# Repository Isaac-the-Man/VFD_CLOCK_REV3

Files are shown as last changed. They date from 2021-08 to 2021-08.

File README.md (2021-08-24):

# VFD_CLOCK_REV3
An arduino-compatible IVL2-7/5 VFD clock, version 3.1.

VFD_demo

(NOTE: flashing is only seen on camera due to high FPS)

## Features
- IVL2-7/5 VFD Display
- Arduino-compatible (programmable via Arduino IDE)
- Built-in extremely accurate real time clock with error less than a second per year, with calendar
- Four NeoPixel RGB LED
- On-board push buttons for setting time, changing brightness, LED pattern, and more
- Micro-USB powered
- In-ciruit temperature sensor
- Automatially saves user settings on shutdown
- Power saving mode: automatically lower brightness at night and turns back on in the morning.

## Hardware
- Atmega328P-PU with external 16MHz cyrstal as the MCU.
- FT232RL for USB to TTL converstion (programming the MCU).
- DS3231M+TRL as the RTC. Includes a temperature sensing feedback circuit for tuning the crystal. Error less than a second per year. A CR2032 external power source is used as a back-up power when the USB is not connected.
- WS2812 NeoPixel RGB LED. A serial and individually-addressable RGB LED.
- Adjustable boost converter (AP3012KTR, replaceable): Boost voltage up to 25V. Adjustable via a potentiometer. Highly efficient.
- Adjustable buck converter (ST1S12GR, replaceable): Buck voltage down to 2V. Adjustable via a potentiometer. Highly efficient.
- MAX6921AUI+ VFD driver: 70V high-side switch with integrated 20-bit shift register.

## Usage
Carefully solder each components on the PCB. Insert a CR2032 battery for backup power (critical for time-keeping). Download `VFD_CLOCK_REV3_FINAL.ino` and upload it to the board via USB using the Arduino IDE, and there you have it. There are a lot more settings available in the code (variables starting with `SET_` are configurable at compile time), but requries further investigation of the code.

## Control Button Manual
This document covers the default behavior of the software. For simplicity, ignoring the left most button (RESET), the rest three buttons are referred as `L`, `M`, and `R` from left to right. Button presses shorter than 2 second is a short press, and a long press if longer.

The default display view is the current time (Hour:Minute). The colon in the middle turns on at even second and off during odd. From this state you can perform the following operation:

### SHORT L Press
Display date and year, each two seconds, then return to normal clock mode.

### SHORT M Press
Display temperature from the DS3231 IC for two seconds, then return.

### SHORT R Press
Display "HELO", for fun.

### LONG L Press
Enters time-set mode. The entire VFD display will start to blink. You can then modify Hour:Minute, Month.Date, and Year in a sequence of steps with `M` and `R` changing the values and `L` advancing the modified steps. After setting the year, another `L` press with bring you back to normal clock mode with the new set time.

### LONG M Press
Enters edit brightness mode. Press `L` to decrease lumin and `R` to increase. Value ranges from 1 ~ 25. The VFD or the LED will blink based on whatever is the target of the edit. Pressing `M` will advances into the next step (first VFD -> LED -> back to normal clock mode).

### LONG R Press
Enters edit LED mode. Press `L` to loop between LED patterns (single color cycle -> serial color cycle -> off -> single color cycle...). Press `M` to fix the current color (freezes the color in the cycle). Press `R` to return to normal clock mode.

Software and Hardware designed by *Isaac_the_Man*, aka *Yu-Kai "Steven" Wang*.
Published under MIT LICENSE

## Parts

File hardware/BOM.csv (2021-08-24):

Query | Qty | Manufacturer | MPN | Octopart URL | Part Description | Description | Schematic Reference | Internal Part Number | Lifecycle | Lead Time | RoHS | Total Qty (@ Batch Size: 3) | SKU | SKU | Packaging | Packaging | Unit Price (@ Batch Size: 3) | Unit Price (@ Batch Size: 3) | In Stock | In Stock | MOQ | MOQ | URL | URL | Distributor [Lowest Price (Selected)] | SKU [Lowest Price (Selected)] | Packaging [Lowest Price (Selected)] | Unit Price (@ Batch Size: 3) [Lowest Price (Selected)] | Line Total [Lowest Price (Selected)] | Batch Total [Lowest Price (Selected)] | In Stock [Lowest Price (Selected)] | MOQ [Lowest Price (Selected)] | URL [Lowest Price (Selected)] | Notes
 |  |  |  |  |  |  |  |  |  |  |  |  | Digi-Key | Mouser | Digi-Key | Mouser | Digi-Key | Mouser | Digi-Key | Mouser | Digi-Key | Mouser | Digi-Key | Mouser
AP3012KTR-G1 | 1 | Diodes Inc. | AP3012KTR-G1 | https://octopart.com/ap3012ktr-g1-diodes+inc.-30954658 | AP3012 Series 16 V 500 mA 1.5 MHz Surface Mount Boost DC-DC Converter - SOT-25 |  | U2 |  |  | 48w | Compliant | 3 | AP3012KTR-G1DICT-ND | 621-AP3012KTR-G1 | Cut Tape | Tape & Reel | 16 | 13.697068 | 133601 | 1250 | 1 | 1 | https://octopart.com/click/track?country=TW&ct=offers&ppid=30954658&sid=459&sig=0920746&vpid=95776337&ai4=706 | https://octopart.com/click/track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 | Mouser | 621-AP3012KTR-G1 | Tape & Reel | 13.697068 | 13.697068 | 41.091204 | 1250 | 1 | https://octopart.com/click/track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 | g
RT5750BHGJ5 | 1 | Richtek | RT5750BHGJ5 | https://octopart.com/rt5750bhgj5-richtek-112268624 | 6V 1A Sync Adj Acot Buck TSOT-25 | replace ST1S12GR | U3 |  |  | 12w |  | 3 | 1028-RT5750BHGJ5CT-ND |  | Cut Tape |  | 23 |  | 2747 |  | 1 |  | https://octopart.com/click/track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 |  | Digi-Key | 1028-RT5750BHGJ5CT-ND | Cut Tape | 23 | 23 | 69 | 2747 | 1 | https://octopart.com/click/track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 | g
ATMEGA328P-PU | 1 | Microchip | ATMEGA328P-PU | https://octopart.com/atmega328p-pu-microchip-77760224 | Microchip - ATMEGA328P-PU - Microcontroller Mcu, 8 Bit, Atmega, 20MHZ, DIP-28 |  | U4 |  | Production (Last Updated: 11 months ago) | 3w | Compliant | 3 | ATMEGA328P-PU-ND | 556-ATMEGA328P-PU | Tube | Tube | 86 | 64.012828 | 39815 | 0 | 1 | 1 | https://octopart.com/click/track?country=TW&ct=offers&ppid=77760224&sid=459&sig=04b47fc&vpid=408716895&ai4=706 | https://octopart.com/click/track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 | Mouser | 556-ATMEGA328P-PU | Tube | 64.012828 | 64.012828 | 192.03848399999998 | 0 | 1 | https://octopart.com/click/track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 | g
MAX6921AUI+ | 1 | Maxim Integrated | MAX6921AUI+ | https://octopart.com/max6921aui%2B-maxim+integrated-39847051 | 20-Output, 76V, Serial-Interfaced VFD Tube Drivers |  | U5 |  | Production (Last Updated: 1 month ago) | 7w | Compliant | 3 | MAX6921AUI+-ND | 700-MAX6921AUI | Tube | Tube | 218 | 208.81040399999998 | 394 | 140 | 1 | 1 | https://octopart.com/click/track?country=TW&ct=offers&ppid=39847051&sid=459&sig=0f40c03&vpid=115957033&ai4=706 | https://octopart.com/click/track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 | Mouser | 700-MAX6921AUI | Tube | 208.81040399999998 | 208.81040399999998 | 626.431212 | 140 | 1 | https://octopart.com/click/track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 | g
DS3231M+TRL | 1 | Maxim Integrated | DS3231M+TRL | https://octopart.com/ds3231m%2Btrl-maxim+integrated-44322454 | Real Time Clock Serial 16-Pin SOIC W T/R |  | RTC |  | Production (Last Updated: 4 months ago) | 52w | Compliant | 3 | DS3231M+TRLCT-ND | 700-DS3231M+TRL | Cut Tape | Tape & Reel | 243 | 244.031436 | 1968 | 2802 | 1 | 1 | https://octopart.com/click/track?country=TW&ct=offers&ppid=44322454&sid=459&sig=0af3bcb&vpid=220250735&ai4=706 | https://octopart.com/click/track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 | Digi-Key | DS3231M+TRLCT-ND | Cut Tape | 243 | 243 | 729 | 1968 | 1 | https://octopart.com/click/track?country=TW&ct=offers&ppid=44322454&sid=459&sig=0af3bcb&vpid=220250735&ai4=706 | g
MF-MSMF050-2 | 1 | Bourns | MF-MSMF050-2 | https://octopart.com/mf-msmf050-2-bourns-28047 | PTC Resettable Fuse 0.5A(hold) 1A(trip) 15V 100A 0.8W 0.15s 0.15Ohm SMD Solder Pad 1812 T/R |  | F1 |  |  | 22w | Compliant | 3 | MF-MSMF050-2CT-ND | 652-MF-MSMF050-2 | Cut Tape | Tape & Reel | 10 | 8.665492 | 1564 | 0 | 1 | 1 | https://octopart.com/click/track?country=TW&ct=offers&ppid=28047&sid=459&sig=0f2ac7d&vpid=1626218&ai4=706 | https://octopart.com/click/track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 | Mouser | 652-MF-MSMF050-2 | Tape & Reel | 8.665492 | 8.665492 | 25.996476 | 0 | 1 | https://octopart.com/click/track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
BLM21PG121SN1D | 1 | Murata | BLM21PG121SN1D | https://octopart.com/blm21pg121sn1d-murata-17751448 | Ferrite Beads Multi-Layer 120Ohm 25% 100MHz 3A 30mOhm DCR 0805 Paper T/R |  | FB1 |  | Production (Last Updated: 1 month ago) | 21w | Compliant | 3 | 490-5986-1-ND | 81-BLM21PG121SN1D | Cut Tape | Tape & Reel | 4 | 3.3543839999999996 | 97 | 12223 | 1 | 1 | https://octopart.com/click/track?country=TW&ct=offers&ppid=17751448&sid=459&sig=06ed73e&vpid=64139726&ai4=706 | https://octopart.com/click/track?country=TW&ct=offers&ppid=17751448&sid=2401&sig=0074331&vpid=37725377&ai4=706 | Mouser | 81-BLM21PG121SN1D | Tape & Reel | 3.3543839999999996 | 3.3543839999999996 | 10.063151999999999 | 12223 | 1 | https://octopart.com/click/track?country=TW&ct=offers&ppid=17751448&sid=2401&sig=0074331&vpid=37725377&ai4=706 | g
CVH201205-2R2M | 1 | Bourns | CVH201205-2R2M | https://octopart.com/cvh201205-2r2m-bourns-101804601 | Inductor Power Shielded Multi-Layer 2.2uH 20% 1MHz Ferrite 0.6A 0.33Ohm DCR 0805 T/R |  | L1 |  |  | 24w |  | 3 | CVH201205-2R2MCT-ND | 652-CVH201205-2R2M | Cut Tape | Tape & Reel | 8 | 6.9883 | 930 | 315 | 1 | 1 | https://octopart.com/click/track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 | https://octopart.com/click/track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 | Mouser | 652-CVH201205-2R2M | Tape & Reel | 6.9883 | 6.9883 | 20.9649 | 315 | 1 | https://octopart.com/click/track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 | g
CB2012T100KR | 1 | Taiyo Yuden | CB2012T100KR | https://octopart.com/cb2012t100kr-taiyo+yuden-19041648 | Inductor Power Chip Wirewound 10uH 10% 2.52MHz Ferrite 0.52A 0.65Ohm DCR 0805 T/R |  | L2 |  |  | 30w | Compliant | 3 | 587-2452-1-ND | 963-CB2012T100KR | Cut Tape | Tape & Reel | 8 | 7.547364 | 4531 | 20910 | 1 | 1 | https://octopart.com/click/track?country=TW&ct=offers&ppid=19041648&sid=459&sig=0621da0&vpid=34090584&ai4=706 | https://octopart.com/click/track?country=TW&ct=offers&ppid=19041648&sid=2401&sig=0b7ecbe&vpid=46007009&ai4=706 | Mouser | 963-CB2012T100KR | Tape & Reel | 7.547364 | 7.547364 | 22.642091999999998 | 20910 | 1 | https://octopart.com/click/track?country=TW&ct=offers&ppid=19041648&sid=2401&sig=0b7ecbe&vpid=46007009&ai4=706 | g
CR0805AFX-1003EAS | 1 | Bourns | CR0805AFX-1003EAS | https://octopart.com/cr0805afx-1003eas-bourns-102743158 | Resistor, AS 0805 100k 1% 125mW TC100 |  | R1 |  |  | 18w |  | 3 | CR0805AFX-1003EASCT-ND | 652-CR0805AFX1003EAS | Cut Tape | Tape & Reel | 3 | 3.3543839999999996 | 6418 | 8175 | 1 | 1 | https://octopart.com/click/track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 | https://octopart.com/click/track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 | Digi-Key | CR0805AFX-1003EASCT-ND | Cut Tape | 3 | 3 | 9 | 6418 | 1 | https://octopart.com/click/track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 | g
CR0805-FX-3302ELF | 1 | Bourns | CR0805-FX-3302ELF | https://octopart.com/cr0805-fx-3302elf-bourns-6075363 | Res Thick Film 0805 33K Ohm 1% 1/8W ±100ppm/°C Molded SMD SMD Paper Tape on Plastic Reel | 33k ohm | R2 |  |  | 18w | Compliant | 3 | CR0805-FX-3302ELFCT-ND | 652-CR0805FX-3302ELF | Cut Tape | Tape & Reel | 3 | 2.7953200000000002 | 5368 | 19443 | 1 | 1 | https://octopart.com/click/track?country=TW&ct=offers&ppid=6075363&sid=459&sig=08bd268&vpid=82229494&ai4=706 | https://octopart.com/click/track?country=TW&ct=offers&ppid=6075363&sid=2401&sig=087c45c&vpid=42422731&ai4=706 | Mouser | 652-CR0805FX-3302ELF | Tape & Reel | 2.7953200000000002 | 2.7953200000000002 | 8.38596 | 19443 | 1 | https://octopart.com/click/track?country=TW&ct=offers&ppid=6075363&sid=2401&sig=087c45c&vpid=42422731&ai4=706 | g
CT-6EP503 | 2 | Nidec Copal | CT-6EP503 | https://octopart.com/ct-6ep503-nidec+copal-91739835 | Res Cermet Trimmer 50K Ohm 10% 1/2W 1(Elec)/1(Mech)Turn 2.6mm (7 X 7 X 5.8mm) Pin Thru-Hole Bulk | 50k pot | R3,R6 |  |  | 9w | Compliant | 6 | CT6EP503-ND |  | Bulk |  | 24 |  | 3295 |  | 1 |  | https://octopart.com/click/track?country=TW&ct=offers&ppid=91739835&sid=459&sig=0ecc308&vpid=449413611&ai4=706 |  | Digi-Key | CT6EP503-ND | Bulk | 24 | 48 | 144 | 3295 | 1 | https://octopart.com/click/track?country=TW&ct=offers&ppid=91739835&sid=459&sig=0ecc308&vpid=449413611&ai4=706 | g
CR0805-FX-4702ELF | 1 | Bourns | CR0805-FX-4702ELF | https://octopart.com/cr0805-fx-4702elf-bourns-3729599 | Res Thick Film 0805 47K Ohm 1% 1/8W ±100ppm/°C Molded SMD SMD Paper Tape on Plastic Reel | 47k | R4 |  |  | 18w | Compliant | 3 | 118-CR0805-FX-4702ELFCT-ND | 652-CR0805FX-4702ELF | Cut Tape | Tape & Reel | 3 | 2.7953200000000002 | 21797 | 100000 | 1 | 1 | https://octopart.com/click/track?country=TW&ct=offers&ppid=3729599&sid=459&sig=0976fb8&vpid=598541444&ai4=706 | https://octopart.com/click/track?country=TW&ct=offers&ppid=3729599&sid=2401&sig=07dd9cb&vpid=37770934&ai4=706 | Mouser | 652-CR0805FX-4702ELF | Tape & Reel | 2.7953200000000002 | 2.7953200000000002 | 8.38596 | 100000 | 1 | https://octopart.com/click/track?country=TW&ct=offers&ppid=3729599&sid=2401&sig=07dd9cb&vpid=37770934&ai4=706 | g
RC0805FR-075K1L | 1 | Yageo | RC0805FR-075K1L | https://octopart.com/rc0805fr-075k1l-yageo-1197477 | Res Thick Film 0805 5.1K Ohm 1% 0.125W(1/8W) ±100ppm/C Pad SMD T/R | 5.1k | R5 |  |  | 20w | Compliant | 3 | 311-5.10KCRCT-ND | 603-RC0805FR-075K1L | Cut Tape | Tape & Reel | 3 | 2.7953200000000002 | 734874 | 86634 | 1 | 1 | https://octopart.com/click/track?country=TW&ct=offers&ppid=1197477&sid=459&sig=03ae3c2&vpid=1162196&ai4=706 | https://octopart.com/click/track?country=TW&ct=offers&ppid=1197477&sid=2401&sig=04391d0&vpid=37935595&ai4=706 | Mouser | 603-RC0805FR-075K1L | Tape & Reel | 2.7953200000000002 | 2.7953200000000002 | 8.38596 | 86634 | 1 | https://octopart.com/click/track?country=TW&ct=offers&ppid=1197477&sid=2401&sig=04391d0&vpid=37935595&ai4=706 | g
RMCF0805JT330R | 2 | Stackpole Electronics | RMCF0805JT330R | https://octopart.com/rmcf0805jt330r-stackpole+electronics-19214550 | Res Thick Film 0805 330 Ohm 5% 0.125W(1/8W) ±200ppm/C Pad SMD Automotive T/R | 330 ohm | R7,R8 |  |  | 24w | Compliant | 6 | RMCF0805JT330RCT-ND |  | Cut Tape |  | 3 |  | 61520 |  | 1 |  | https://octopart.com/click/track?country=TW&ct=offers&ppid=19214550&sid=459&sig=023e3ea&vpid=34422711&ai4=706 |  | Digi-Key | RMCF0805JT330RCT-ND | Cut Tape | 3 | 6 | 18 | 61520 | 1 | https://octopart.com/click/track?country=TW&ct=offers&ppid=19214550&sid=459&sig=023e3ea&vpid=34422711&ai4=706 | g
732-7657-1-ND | 1 | Würth Elektronik | 885012207025 | https://octopart.com/885012207025-w%C3%BCrth+elektronik-65419799 | Multilayer Ceramic Capacitor, Wcap-Csgp Series, 4.7 F, 10%, X7R, 10 V, 0805 [2012 Metric] Rohs Compliant: Yes | 4.7uf X7R | C1 |  |  | 52w | Compliant | 3 | 732-7657-1-ND | 710-885012207025 | Cut Tape | Tape & Reel | 24 | 22.362560000000002 | 15362 | 0 | 1 | 1 | https://octopart.com/click/track?country=TW&ct=offers&ppid=65419799&sid=459&sig=0004de7&vpid=229679464&ai4=706 | https://octopart.com/click/track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 | Mouser | 710-885012207025 | Tape & Reel | 22.362560000000002 | 22.362560000000002 | 67.08768 | 0 | 1 | https://octopart.com/click/track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 | g
885012207026 | 1 | Würth Elektronik | 885012207026 | https://octopart.com/885012207026-w%C3%BCrth+elektronik-65419800 | Multilayer Ceramic Capacitor, Wcap-Csgp Series, 10 F, 10%, X7r, 10 V, 0805 [2012 Metric] | 10uf X7R | C2 |  |  | 50w | Compliant | 3 | 732-7658-1-ND | 710-885012207026 | Cut Tape | Tape & Reel | 34 | 32.425712 | 198 | 0 | 1 | 1 | https://octopart.com/click/track?country=TW&ct=offers&ppid=65419800&sid=459&sig=01b98b0&vpid=229679467&ai4=706 | https://octopart.com/click/track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 | Mouser | 710-885012207026 | Tape & Reel | 32.425712 | 32.425712 | 97.27713599999998 | 0 | 1 | https://octopart.com/click/track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 | g
VJ0805Y104KXXCW1BC | 12 | Vishay | VJ0805Y104KXXCW1BC | https://octopart.com/vj0805y104kxxcw1bc-vishay-39476220 | Cap Ceramic 0.1uF 25V X7R 10% SMD 0805 125°C Paper T/R | 0.1uf 25V | C5,C6,C9,C8,C13,C7,C14,C15,C16,C17,C18,C20 |  |  | 30w | Compliant | 36 | 720-1537-1-ND | 77-VJ0805Y104KXXCBC | Cut Tape | Tape & Reel | 5.5 | 5.031575999999999 | 28514 | 12572 | 1 | 1 | https://octopart.com/click/track?country=TW&ct=offers&ppid=39476220&sid=459&sig=0555a1b&vpid=263211457&ai4=706 | https://octopart.com/click/track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 | Mouser | 77-VJ0805Y104KXXCBC | Tape & Reel | 5.031575999999999 | 60.37891199999999 | 181.13673599999998 | 12572 | 1 | https://octopart.com/click/track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 | g
885012107018 | 1 | Würth Elektronik | 885012107018 | https://octopart.com/885012107018-w%C3%BCrth+elektronik-65419743 | Multilayer Ceramic Capacitor, Wcap-Csgp Series, 4.7 F, 20%, X5R, 25 V, 0805 [2012 Metric] Rohs Compliant: Yes | 4.7uf 25V | C10 |  |  | 38w | Compliant | 3 | 732-7628-1-ND | 710-885012107018 | Cut Tape | Tape & Reel | 5 | 4.752044000000001 | 688 | 0 | 1 | 1 | https://octopart.com/click/track?country=TW&ct=offers&ppid=65419743&sid=459&sig=0b01c17&vpid=229678808&ai4=706 | https://octopart.com/click/track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 | Mouser | 710-885012107018 | Tape & Reel | 4.752044000000001 | 4.752044000000001 | 14.256132000000001 | 0 | 1 | https://octopart.com/click/track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 | g
MBR0580S1-7 | 1 | Diodes Inc. | MBR0580S1-7 | https://octopart.com/mbr0580s1-7-diodes+inc.-53081572 | Rectifier Diode Schottky 80V 0.5A 2-Pin SOD-123 T/R |  | D1 |  |  | 39w | Compliant | 3 | MBR0580S1-7DICT-ND | 621-MBR0580S1-7 | Cut Tape | Tape & Reel | 10 | 8.945024 | 0 | 3182 | 1 | 1 | https://octopart.com/click/track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 | https://octopart.com/click/track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 | Mouser | 621-MBR0580S1-7 | Tape & Reel | 8.945024 | 8.945024 | 26.835072 | 3182 | 1 | https://octopart.com/click/track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 | g
LS R976-NR-1 | 1 | Osram Opto | LS R976-NR-1 | https://octopart.com/ls+r976-nr-1-osram+opto-31093945 | LED Uni-Color Super Red 645nm 2-Pin Chip 0805(2012Metric) T/R | RED LED | D2 |  | Production (Last Updated: 1 year ago) | 14w | Compliant | 3 | 475-1278-1-ND | 720-LSR976-NR-1 | Cut Tape | Tape & Reel | 8 | 7.547364 | 146851 | 725157 | 1 | 1 | https://octopart.com/click/track?country=TW&ct=offers&ppid=31093945&sid=459&sig=0cf7e39&vpid=90899042&ai4=706 | https://octopart.com/click/track?country=TW&ct=offers&ppid=31093945&sid=2401&sig=0fb7117&vpid=90919824&ai4=706 | Mouser | 720-LSR976-NR-1 | Tape & Reel | 7.547364 | 7.547364 | 22.642091999999998 | 725157 | 1 | https://octopart.com/click/track?country=TW&ct=offers&ppid=31093945&sid=2401&sig=0fb7117&vpid=90919824&ai4=706 | g
885012207051 | 2 | Würth Elektronik | 885012207051 | https://octopart.com/885012207051-w%C3%BCrth+elektronik-65419825 | Cap, 1ΜF, 16V, 10%, X7R, 0805 | 1uf X7R | C3,C4 |  |  | 38w | Compliant | 6 | 732-7664-1-ND | 710-885012207051 | Cut Tape | Tape & Reel | 3 | 2.7953200000000002 | 12005 | 244 | 1 | 1 | https://octopart.com/click/track?country=TW&ct=offers&ppid=65419825&sid=459&sig=05187b3&vpid=229679542&ai4=706 | https://octopart.com/click/track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 | Mouser | 710-885012207051 | Tape & Reel | 2.7953200000000002 | 5.5906400000000005 | 16.77192 | 244 | 1 | https://octopart.com/click/track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 | g
404-1291-1-ND | 1 | Stanley Electric | VCDG1112H-4BY3C-TR | https://octopart.com/vcdg1112h-4by3c-tr-stanley+electric-77934853 | LED Uni-Color Green 522nm T/R | GREEN LED | D3 |  |  | 11w |  | 3 | 404-1291-1-ND | 327-VCDG1112H4BY3CTR | Cut Tape | Tape & Reel | 17 | 14.535664 | 95885 | 3856 | 1 | 1 | https://octopart.com/click/track?country=TW&ct=offers&ppid=77934853&sid=459&sig=03d5507&vpid=487593896&ai4=706 | https://octopart.com/click/track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 | Mouser | 327-VCDG1112H4BY3CTR | Tape & Reel | 14.535664 | 14.535664 | 43.606992000000005 | 3856 | 1 | https://octopart.com/click/track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 | g
RMCF0805JT4K70 | 6 | Stackpole Electronics | RMCF0805JT4K70 | https://octopart.com/rmcf0805jt4k70-stackpole+electronics-19214579 | Res Thick Film 0805 4.7K Ohm 5% 0.125W(1/8W) ±200ppm/C Pad SMD Automotive T/R | 4.7k | R11,R12,R13,R14,R9,R10 |  |  | 24w | Compliant | 18 | RMCF0805JT4K70CT-ND |  | Cut Tape |  | 0.7 |  | 588 |  | 1 |  | https://octopart.com/click/track?country=TW&ct=offers&ppid=19214579&sid=459&sig=0636edd&vpid=34422761&ai4=706 |  | Digi-Key | RMCF0805JT4K70CT-ND | Cut Tape | 0.7 | 4.199999999999999 | 12.6 | 588 | 1 | https://octopart.com/click/track?country=TW&ct=offers&ppid=19214579&sid=459&sig=0636edd&vpid=34422761&ai4=706 | g
2-1825027-0 | 4 | TE Connectivity | 2-1825027-0 | https://octopart.com/2-1825027-0-te+connectivity-42271502 | Switch Tactile OFF (ON) SPST Round Button PC Pins 0.05A 24VDC 1.57N Thru-Hole Loose Piece | switch | SW1,SW2,SW3,SW4 |  | Production (Last Updated: 1 day ago) | 18w | Compliant | 12 | 450-1661-ND | 506-2-1825027-0 | Bulk | Bulk | 7.8 | 6.569001999999999 | 328 | 28508 | 1 | 1 | https://octopart.com/click/track?country=TW&ct=offers&ppid=42271502&sid=459&sig=044b097&vpid=198635029&ai4=706 | https://octopart.com/click/track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 | Mouser | 506-2-1825027-0 | Bulk | 6.569001999999999 | 26.276007999999997 | 78.828024 | 28508 | 1 | https://octopart.com/click/track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 | g
885012007053 | 2 | Würth Elektronik | 885012007053 | https://octopart.com/885012007053-w%C3%BCrth+elektronik-65419633 | Cap, 22PF, 50V, 5%, C0G/NP0, 0805 | 22pf | C11,C12 |  |  | 38w | Compliant | 6 | 732-7848-1-ND | 710-885012007053 | Cut Tape | Tape & Reel | 3 | 2.7953200000000002 | 4343 | 0 | 1 | 1 | https://octopart.com/click/track?country=TW&ct=offers&ppid=65419633&sid=459&sig=0c15f11&vpid=229678353&ai4=706 | https://octopart.com/click/track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 | Mouser | 710-885012007053 | Tape & Reel | 2.7953200000000002 | 5.5906400000000005 | 16.77192 | 0 | 1 | https://octopart.com/click/track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 | g
AS-16.000-18 | 1 | Raltron Electronics | AS-16.000-18 | https://octopart.com/as-16.000-18-raltron+electronics-973373 | Crystal 16MHz; +/-50ppm; 2-Pin HC-49-S | 16mhz crystal | X1 |  | Production (Last Updated: 1 year ago) | 12w | Compliant | 3 | 2151-AS-16.000-18-ND |  | Bulk |  | 6 |  | 2141 |  | 1 |  | https://octopart.com/click/track?country=TW&ct=offers&ppid=973373&sid=459&sig=085a54e&vpid=572660951&ai4=706 |  | Digi-Key | 2151-AS-16.000-18-ND | Bulk | 6 | 6 | 18 | 2141 | 1 | https://octopart.com/click/track?country=TW&ct=offers&ppid=973373&sid=459&sig=085a54e&vpid=572660951&ai4=706 | g
3034TR | 1 | Keystone | 3034TR | https://octopart.com/3034tr-keystone-26459610 | Coin Cell Battery Holders COIN CELL RETAINER T APE/REEL 500PC | 3.3V battery | J1 |  |  | 6w | Compliant | 3 | 36-3034CT-ND | 534-3034TR | Cut Tape | Tape & Reel | 14 | 12.019876 | 98709 | 23517 | 1 | 1 | https://octopart.com/click/track?country=TW&ct=offers&ppid=26459610&sid=459&sig=0ade4c3&vpid=212425186&ai4=706 | https://octopart.com/click/track?country=TW&ct=offers&ppid=26459610&sid=2401&sig=04a6987&vpid=76876656&ai4=706 | Mouser | 534-3034TR | Tape & Reel | 12.019876 | 12.019876 | 36.059628000000004 | 23517 | 1 | https://octopart.com/click/track?country=TW&ct=offers&ppid=26459610&sid=2401&sig=04a6987&vpid=76876656&ai4=706 | g
1528-1104-ND | 1 | Adafruit Industries | 1655 | https://octopart.com/1655-adafruit+industries-51490158 | NeoPixel 5050 RGB LED with Integrated Driver Chip - 10 Pack | RGB LED 10 pack | D4,D5,D6,D7 |  |  | 2w | Compliant | 3 | 1528-1104-ND | 485-1655 | Strip |  | 138 | 125.7894 | 762 | 3892 | 1 | 1 | https://octopart.com/click/track?country=TW&ct=offers&ppid=51490158&sid=459&sig=0c35518&vpid=192824541&ai4=706 | https://octopart.com/click/track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 | Mouser | 485-1655 |  | 125.7894 | 125.7894 | 377.3682 | 3892 | 1 | https://octopart.com/click/track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 | g
720-1754-1-ND | 1 | Vishay | VJ0805Y104KXARW1BC | https://octopart.com/vj0805y104kxarw1bc-vishay-42059196 | Cap Ceramic 0.1uF 50V X7R 10% SMD 0805 125°C Blister T/R | 0.1uf 50V | C19 |  |  | 30w | Compliant | 3 | 720-1754-1-ND | 77-VJ0805Y104KXARBC | Cut Tape | Tape & Reel | 8 | 5.870171999999999 | 715 | 41675 | 1 | 1 | https://octopart.com/click/track?country=TW&ct=offers&ppid=42059196&sid=459&sig=0da8291&vpid=464290460&ai4=706 | https://octopart.com/click/track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 | Mouser | 77-VJ0805Y104KXARBC | Tape & Reel | 5.870171999999999 | 5.870171999999999 | 17.610515999999997 | 41675 | 1 | https://octopart.com/click/track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 | g
EEE-1AA470WR | 1 | Panasonic | EEE-1AA470WR | https://octopart.com/eee-1aa470wr-panasonic-55597942 | Cap Aluminum 47uF 10V 20% (5 X 5.4mm) SMD 43mA 1000h 85°C T/R | 47uf | C21 |  | Production (Last Updated: 7 months ago) | 50w | Compliant | 3 | PCE3875CT-ND | 667-EEE-1AA470WR | Cut Tape | Tape & Reel | 11 | 9.783619999999999 | 459 | 6 | 1 | 1 | https://octopart.com/click/track?country=TW&ct=offers&ppid=55597942&sid=459&sig=04da77f&vpid=188054707&ai4=706 | https://octopart.com/click/track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 | Mouser | 667-EEE-1AA470WR | Tape & Reel | 9.783619999999999 | 9.783619999999999 | 29.350859999999997 | 6 | 1 | https://octopart.com/click/track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 | g
609-4618-1-ND | 1 | Amphenol ICC / FCI | 10118194-0001LF | https://octopart.com/10118194-0001lf-amphenol+icc+%2F+fci-90333083 | Conn Micro USB 2.0 Type B RCP 5 POS 0.65mm Solder RA SMD 5 Terminal 1 Port T/R | USB | USB |  |  | 15w | Compliant | 3 | 609-4618-1-ND | 649-10118194-0001LF | Cut Tape | Tape & Reel | 15 | 12.019876 | 297381 | 65229 | 1 | 1 | https://octopart.com/click/track?country=TW&ct=offers&ppid=90333083&sid=459&sig=0673512&vpid=531263951&ai4=706 | https://octopart.com/click/track?country=TW&ct=offers&ppid=90333083&sid=2401&sig=0bd8cbc&vpid=45455347&ai4=706 | Mouser | 649-10118194-0001LF | Tape & Reel | 12.019876 | 12.019876 | 36.059628000000004 | 65229 | 1 | https://octopart.com/click/track?country=TW&ct=offers&ppid=90333083&sid=2401&sig=0bd8cbc&vpid=45455347&ai4=706
FT232RL-REEL | 1 | FTDI | FT232RL-REEL | https://octopart.com/ft232rl-reel-ftdi-19172117 | USB Controller, 3MBd, USB2.0, 1.8 - 5.25 V, 28-Pin SSOP, USBmadeEZ-UART Series |  |  |  |  | 33w | Compliant | 3 | 768-1007-6-ND | 895-FT232RL | Custom Reel | Tape & Reel | 154 | 131.38004 | 0 | 0 | 1 | 1 | https://octopart.com/click/track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 | https://octopart.com/click/track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 | Mouser | 895-FT232RL | Tape & Reel | 131.38004 | 131.38004 | 394.14012 | 0 | 1 | https://octopart.com/click/track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

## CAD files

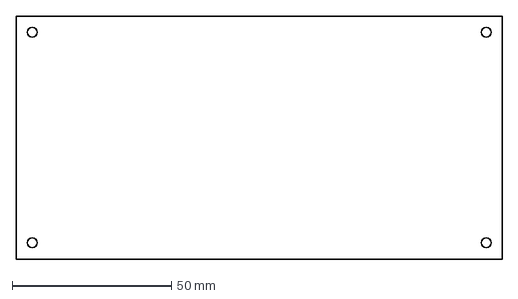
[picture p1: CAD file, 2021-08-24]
hardware/Acrylic Case/vfd_back.dxf
152.4 x 76.2 mm

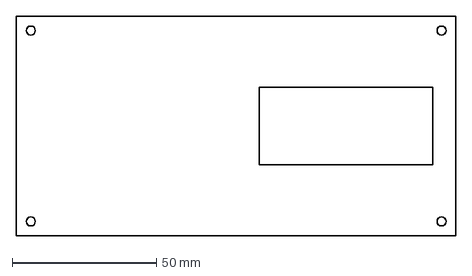
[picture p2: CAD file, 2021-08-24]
hardware/Acrylic Case/vfd_front.dxf
152.4 x 76.2 mm

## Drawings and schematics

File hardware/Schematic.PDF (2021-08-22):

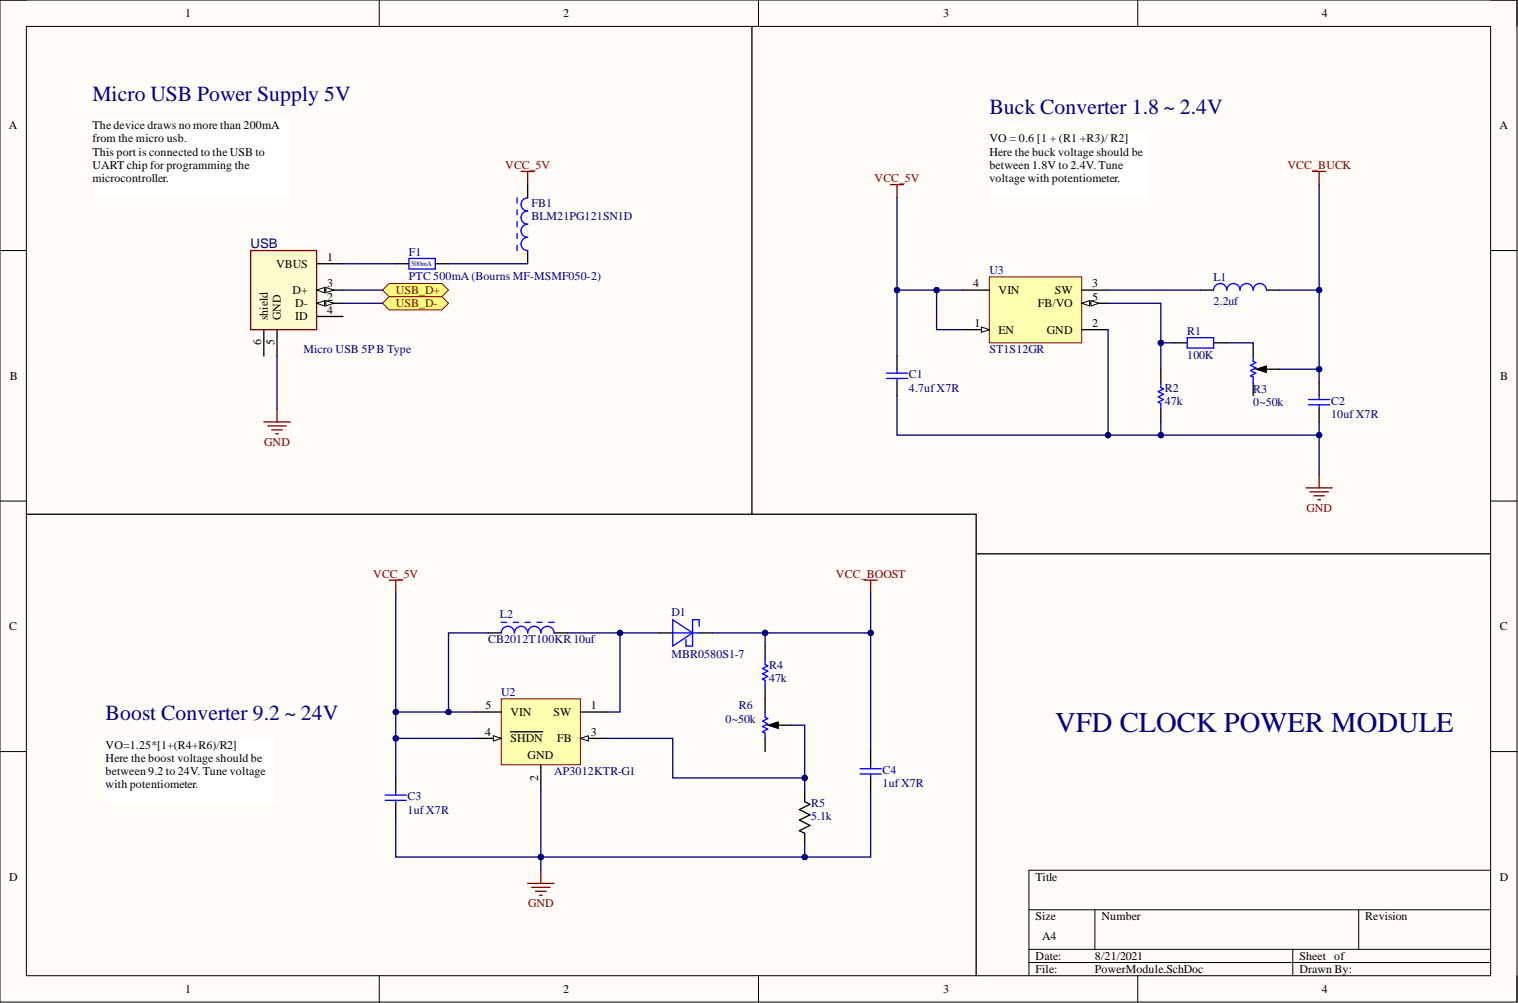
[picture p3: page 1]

Micro USB Power Supply 5V

The device draws no more than 200mA
from the micro usb.
This port is connected to the USB to
UART chip for programming the
microcontroller.

Here the buck voltage should be
between 1.8V to 2.4V. Tune

Here the boost voltage should be
between 9.2 to 24V. Tune voltage
with potentiometer.

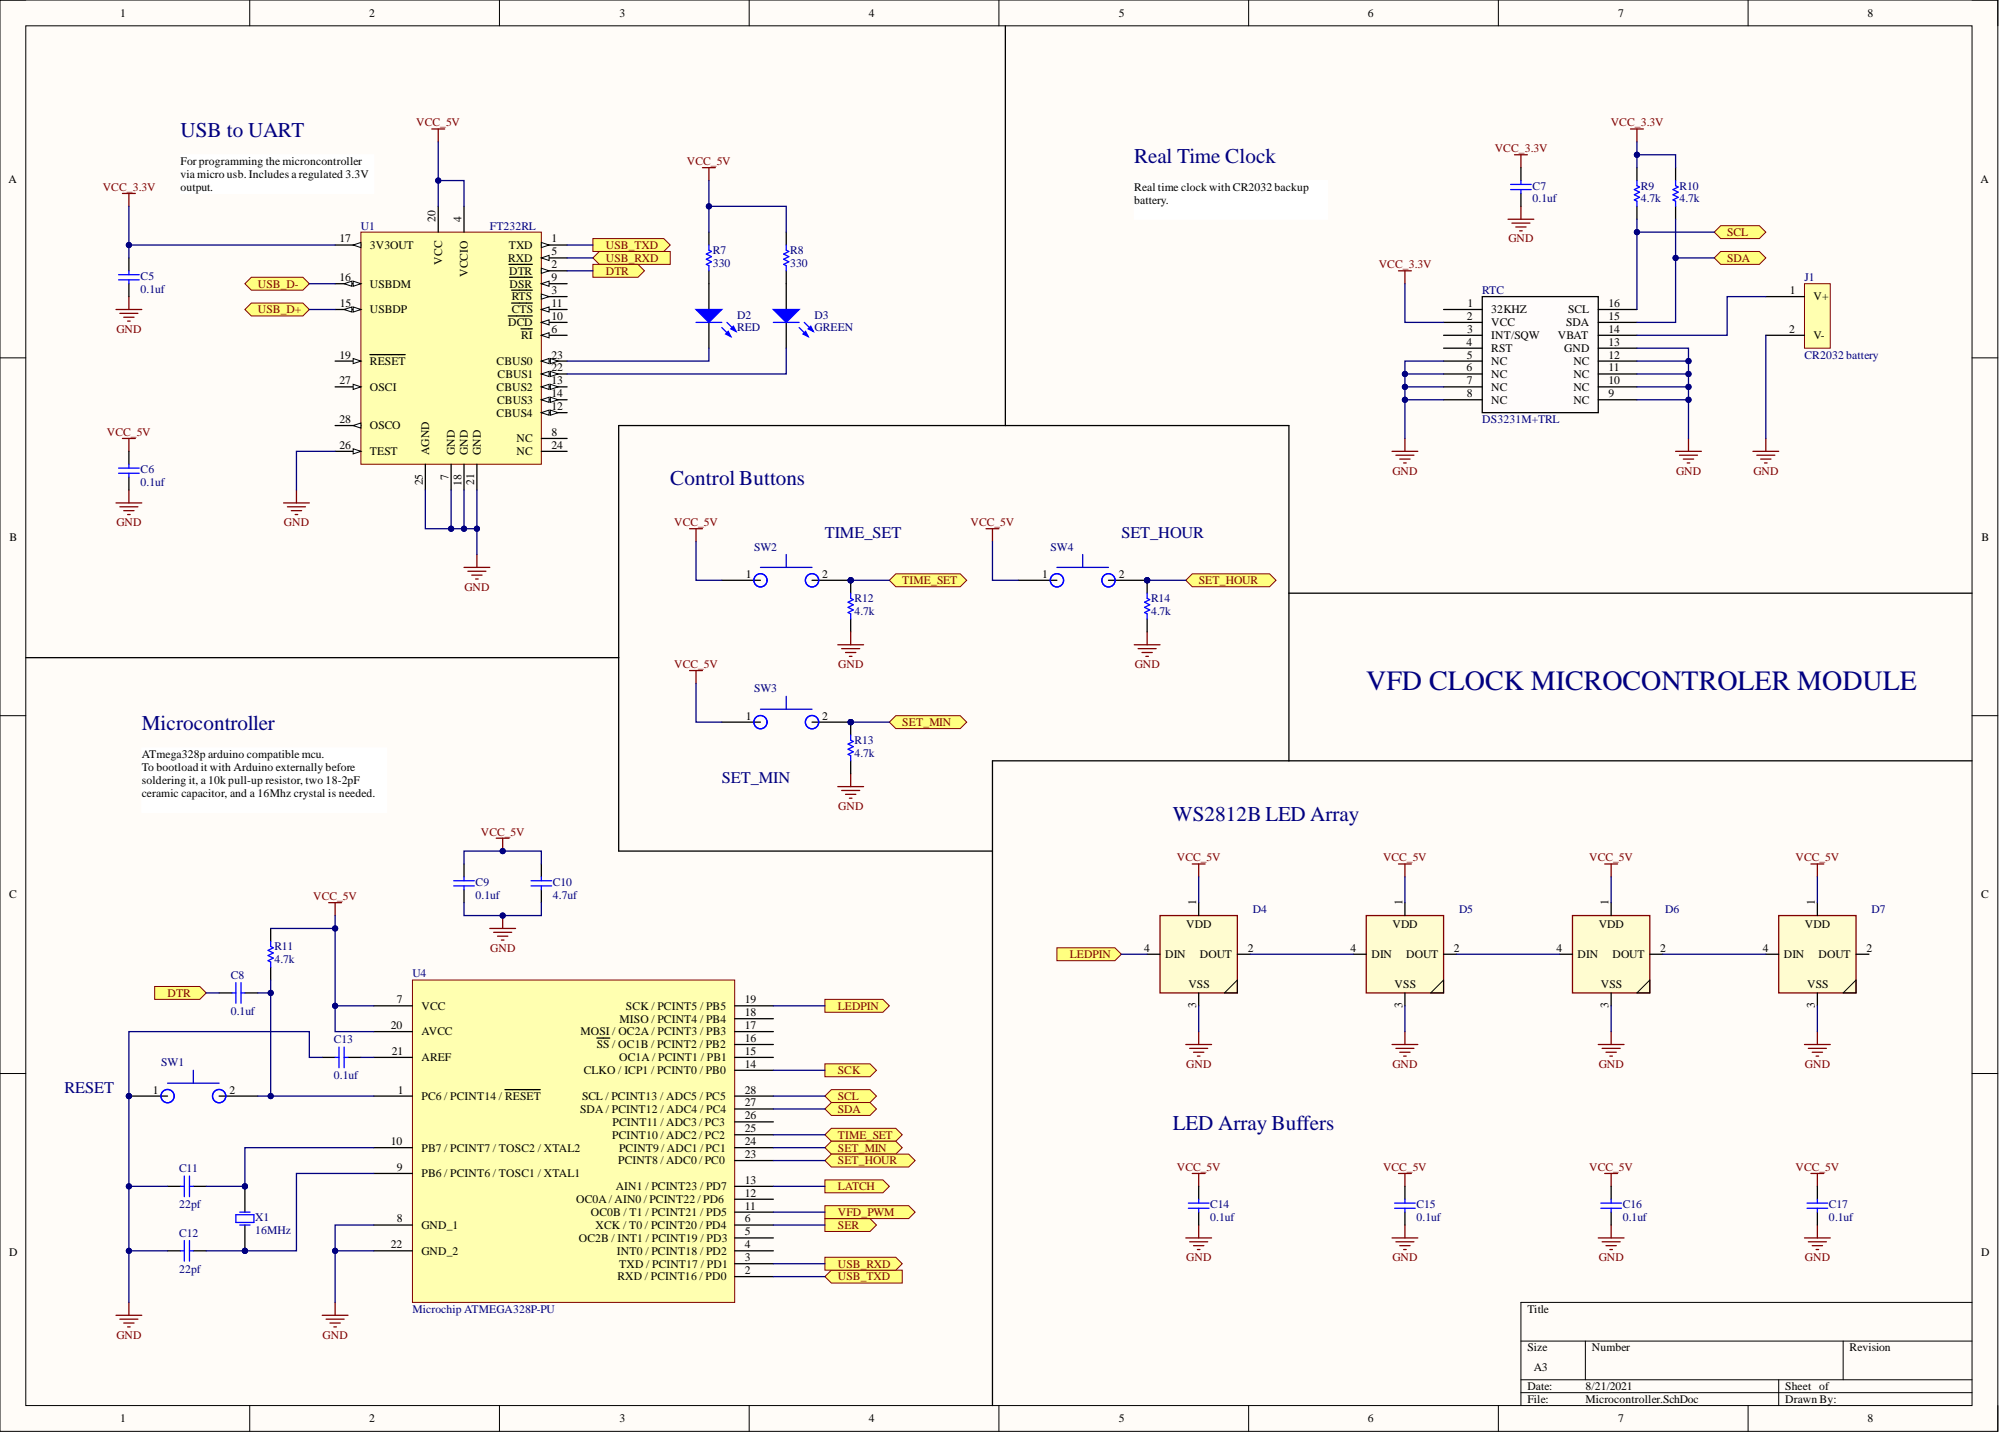
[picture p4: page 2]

For programming the microncontroller
via micro usb. Includes a regulated 3.3V
output.

Real time clock with CR2032 backup
battery.

VFD CLOCK MICROCONTROLER MODULE

ATmega328p arduino compatible mcu.
To bootload it with Arduino externally before
soldering it, a 10k pull-up resistor, two 18-2pF
ceramic capacitor, and a 16Mhz crystal is needed.

PB6 / PCINT6 / TOSC1 / XTAL1 9

GND_1 8

GND_2 22

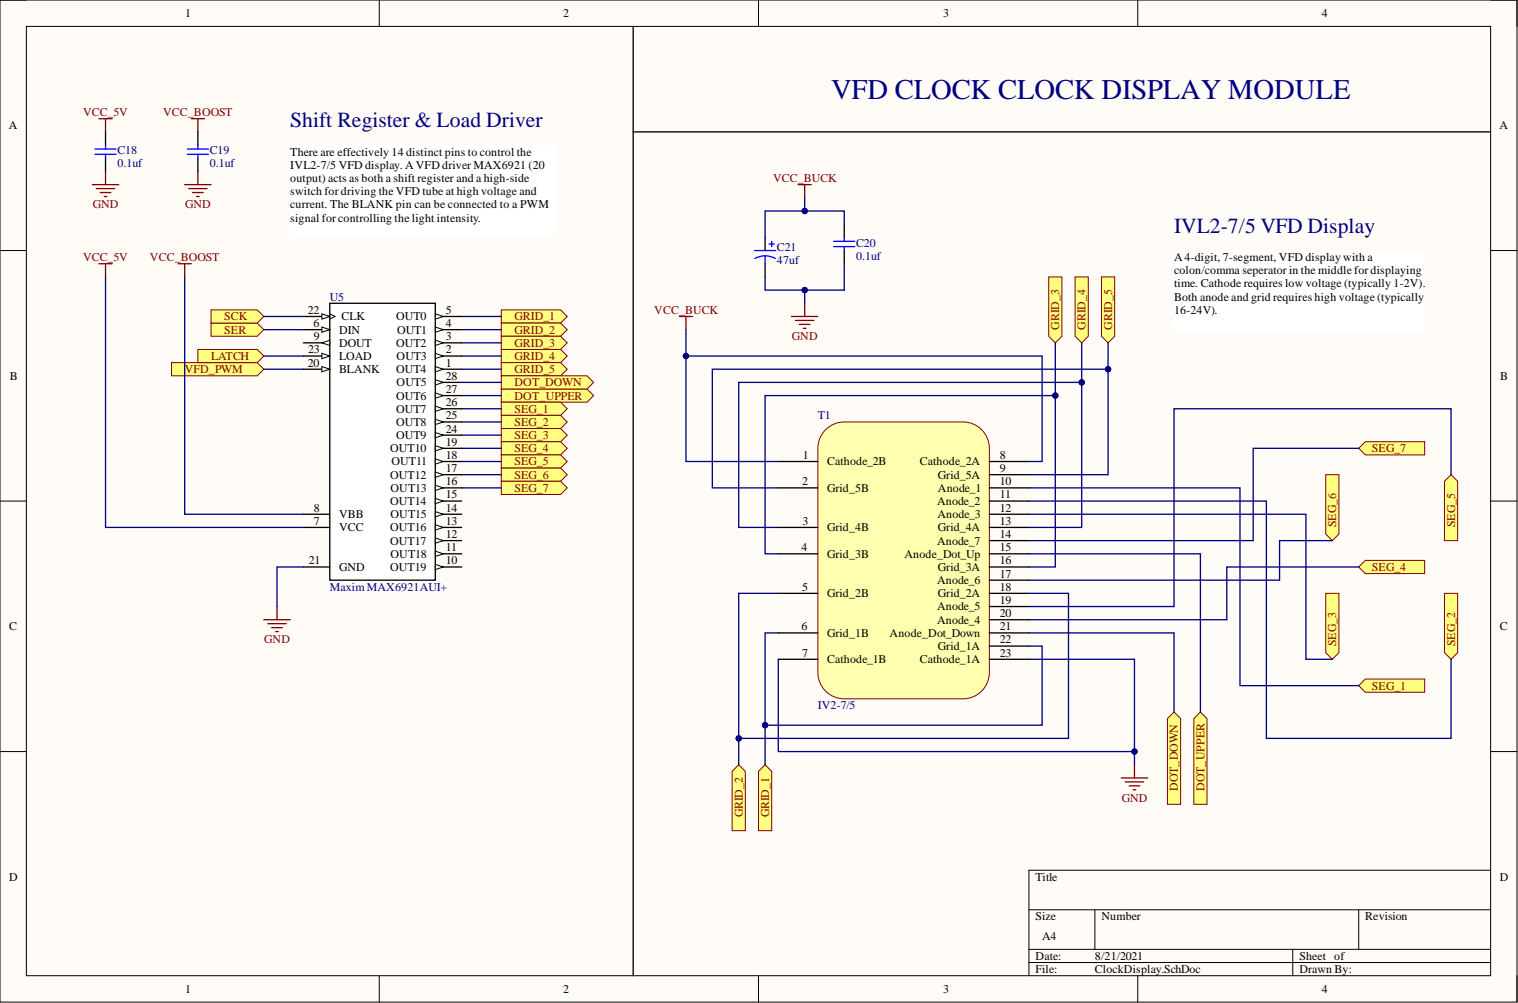
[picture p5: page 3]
IVL2-7/5 VFD Display; o co ver MA; t) act; ift reg; ter an; tch for; tage an; n can; o a PWM; le for; ime. Cat; de req; tage (t; d req; Y MODULE; 8 BLANK

VFD CLOCK CLOCK DISPLA

Shift Register & Load Driver

here are effect

nal for co

9 Gri d _ 5 A 2 1 0 Gri d _ 5 B A n o d e_ 1 1 1 A n o d e_ 2 1 2 A n o d e_ 3 3 1 3 Gri d _ 4 B Gri d _4 A 1 4 A n o d e_ 7 4 1 5

1 9 A n o d e_ 5 2 0 A n o d e_4 6 2 1 Gri d _ 1 B A n o de_ D o t_D o w n 2 2 Gri d _ 1 A

7 2 3 Cat h o d e_ 1 B Cat h o d e_ 1 A

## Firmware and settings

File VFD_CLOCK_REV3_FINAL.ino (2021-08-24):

/*
   IVL2-7/5 VFD CLOCK REV 3.1 SOFTWARE
   WRITTEN BY ISAAC_THE_MAN
   SEE PROJECT ON https://github.com/Isaac-the-Man/VFD_CLOCK_REV3
   LAST UPDATED 8/21/2021
   MIT LICENSE
*/
#include <DS3231M.h>  // Include the DS3231M RTC library
#include <Adafruit_NeoPixel.h>  // RGB LED library
#include <EEPROM.h> // read/write user settings


// Setting constants
const int SET_LONG_PRESS_DUR = 2000;  // duration required to be qualified as a long press, in millis.
const int SET_LED_UPDATE_INTERVAL = 50;  // interval for LED to change color, in millis
const int SET_EEPROM_ADDR = 0;
const int SET_EEPROM_KEY_ADDR = 64;
const int SET_EEPROM_KEY = 11;  // for data integrity check
const int SET_LED_FLICKER_INTERVAL = 200;
const int SET_VFD_FLICKER_INTERVAL = 200;
const int SET_CLOCK_SHORT_DUR = 2000; // duration of short displays such as date and temperature, in millis.
const int SET_TEMP_OFFSET = -500; // 100th of degrees
const int SET_POWER_SAVING_ON_TIME[] = {23, 59};
const int SET_POWER_SAVING_OFF_TIME[] = {7, 0};
const int SET_POWER_SAVING_LUMIN = 205;
const int SET_POWER_SAVING_LED_LUMIN = 15;
const int SET_LED_VALUE = 128;
const int SET_LED_SATURATION = 128;
const int SET_GREETING_WORDS[] = { -1, -1, -1, -1, 14, 0, 15, 16, -1, 17, 0, 18, -1, 19, 12, 12, -1, 20, 21, 12, -1, -1, -1, -1}; // Now you see me
const int SET_GREETING_LENGTH = 24;
const int SET_GREETING_CHAR_DUR = 200;

// VFD display pin
const int PIN_VFD_DIN = 4;
const int PIN_VFD_PWM = 5;
const int PIN_VFD_LATCH = 7;
const int PIN_VFD_CLK = 8;

// Control buttons pin
const int PIN_BTN_L = A2;
const int PIN_BTN_M = A1;
const int PIN_BTN_R = A0;

// RGB LED pin
const int PIN_LED = 13;

// Display Number Constants: segment 1 ~ 7
const int NUM_0[] = {HIGH, HIGH, HIGH, LOW, HIGH, HIGH, HIGH};
const int NUM_1[] = {LOW, HIGH, LOW, LOW, HIGH, LOW, LOW};
const int NUM_2[] = {HIGH, LOW, HIGH, HIGH, HIGH, LOW, HIGH};
const int NUM_3[] = {HIGH, HIGH, LOW, HIGH, HIGH, LOW, HIGH};
const int NUM_4[] = {LOW, HIGH, LOW, HIGH, HIGH, HIGH, LOW};
const int NUM_5[] = {HIGH, HIGH, LOW, HIGH, LOW, HIGH, HIGH};
const int NUM_6[] = {HIGH, HIGH, HIGH, HIGH, LOW, HIGH, HIGH};
const int NUM_7[] = {LOW, HIGH, LOW, LOW, HIGH, HIGH, HIGH};
const int NUM_8[] = {HIGH, HIGH, HIGH, HIGH, HIGH, HIGH, HIGH};
const int NUM_9[] = {HIGH, HIGH, LOW, HIGH, HIGH, HIGH, HIGH};
const int ALP_C[] = {HIGH, LOW, HIGH, LOW, LOW, HIGH, HIGH};  //10
const int ALP_H[] = {LOW, HIGH, HIGH, HIGH, HIGH, HIGH, LOW}; //11
const int ALP_E[] = {HIGH, LOW, HIGH, HIGH, LOW, HIGH, HIGH}; //12
const int ALP_L[] = {HIGH, LOW, HIGH, LOW, LOW, HIGH, LOW}; //13
const int ALP_N[] = {LOW, HIGH, HIGH, LOW, HIGH, HIGH, HIGH};  // 14
const int ALP_W1[] = {HIGH, HIGH, HIGH, LOW, HIGH, HIGH, LOW};  // 15
const int ALP_W2[] = {HIGH, HIGH, LOW, LOW, HIGH, LOW, LOW};  // 16
const int ALP_Y[] = {HIGH, HIGH, LOW, HIGH, HIGH, HIGH, LOW};  // 17
const int ALP_U[] = {HIGH, HIGH, HIGH, LOW, HIGH, HIGH, LOW};  // 18
const int ALP_S[] = {HIGH, HIGH, LOW, HIGH, LOW, HIGH, HIGH};  // 19
const int ALP_M1[] = {LOW, HIGH, HIGH, LOW, HIGH, HIGH, HIGH};  // 20
const int ALP_M2[] = {LOW, HIGH, LOW, LOW, HIGH, LOW, HIGH};  // 21


// Time Constants
const int YEAR = 0;
const int MONTH = 1;
const int DATE = 2;
const int HOUR = 3;
const int MIN = 4;
const int SEC = 5;

// state variables
int STATE_LUMIN = 255;  // VFD brightness level
int STATE_TIME[] = {2021, 12, 16, 12, 0, 0};  // year, month, date, hour, minute, second
int STATE_MODE = 0; // 0: clock mode; 1: edit time mode; 2: brightness mode; 3: color mode;
int STATE_LED_LUMIN = 55;
int STATE_LED_MODE = 0;
int STATE_LED_HUE = 0;  // fixed color hue
bool STATE_LED_FIXED = false; // loop color or not
int STATE_LED_FLICKER = false;  // flicker mode indicates the user is editing LED related settings
int STATE_DISPLAY[] = {0, 0, 0, 0, 0}; // digit, digit, colon, digit, digit
bool STATE_VFD_FLICKER = false; // VFD blink or not
int STATE_TEMP = 0; // temperature in Celsius
bool STATE_POWER_SAVING_ON = false;

// button temp variables
int BTN_VAL_L = LOW;
int BTN_VAL_M = LOW;
int BTN_VAL_R = LOW;
int BTN_PREV_VAL_L = LOW;
int BTN_PREV_VAL_M = LOW;
int BTN_PREV_VAL_R = LOW;
unsigned long BTN_RISIN_TIME_L = 0; // timestamp of rising edge
unsigned long BTN_RISIN_TIME_M = 0; // timestamp of rising edge
unsigned long BTN_RISIN_TIME_R = 0; // timestamp of rising edge
bool BTN_LOCK_L = false;
bool BTN_LOCK_M = false;
bool BTN_LOCK_R = false;

// Clock mode temp variables
int CLOCK_MODE = 0; // 0 for normal clock; 1 for Date; 2 for Year; 3 for Hello
int CLOCK_DATE_YEAR_MODE = 0; // 0 for DATE, 1 for YEAR
unsigned long CLOCK_DATE_YEAR_SHOW_TIME = 0;
unsigned long CLOCK_TEMP_TIME = 0;
unsigned long CLOCK_GREETING_TIME = 0;
int CLOCK_GREETING_INDEX = 0;

// Time Edit Mode temp variables
int TIME_SET_LEVEL = 0; // indicates which part of the time is in on display: 0 for HH::mm, 1 for Date, 2 for Year
int TIME_TEMP_TIME[] = {2021, 12, 16, 12, 0, 0};  // stores edited variables

// Brightness control temp variables
int LUMIN_SET_LEVEL = 0;  // indcates which part of the time is in on display. 0 for VFD display and 1 for LED

// RGB LED temp variables
unsigned long LED_LAST_TIME = 0;
unsigned long LED_LAST_FLICKER = 0;
bool LED_FLICKER_ON = true;
uint32_t color1 = 0;
uint32_t color2 = 0;
uint32_t color3 = 0;
uint32_t color4 = 0;

// VFD display temp variables
int VFD_TEMP[14] = {0}; // initialize to all 0
unsigned long VFD_LAST_FLICKER = 0;
bool VFD_FLICKER_ON = true;

// Power saving temp variables
int POWER_SAVING_PREV_LUMIN = 245;
int POWER_SAVING_PREV_LED_LUMIN = 5;

// EEPROM data
struct ClockConfig {
  int lumin;
  int led_lumin;
  int led_mode;
  int led_hue;
  bool led_fixed;
  bool power_saving_on;
  int power_saving_prev_lumin;
  int power_saving_prev_led_lumin;
};

// RTC setup
DS3231M_Class DS3231M;

// RGB LED setup
Adafruit_NeoPixel strip(4, PIN_LED, NEO_GRB + NEO_KHZ800);

void setup() {
  Serial.begin(9600);
  // Setup VFD
  pinMode(PIN_VFD_PWM, OUTPUT);
  pinMode(PIN_VFD_DIN, OUTPUT);
  pinMode(PIN_VFD_LATCH, OUTPUT);
  pinMode(PIN_VFD_CLK, OUTPUT);
  // Setup Control buttons
  pinMode(PIN_BTN_L, INPUT);
  pinMode(PIN_BTN_M, INPUT);
  pinMode(PIN_BTN_R, INPUT);
  // load settings
  loadConfig();
  // Setup RGB LED
  strip.begin();
  strip.show();
  strip.setBrightness(STATE_LED_LUMIN);
  // Connect to RTC
  while (!DS3231M.begin()) {
    Serial.println(F("FATAL ERROR: Unable to find RTC DS3231M. Checking again in 3s."));
    delay(3000);
  }
}

void loop() {
  // load time from RTC
  getTime();
  powerSaving();
  // Controls
  detectControls();
  // VFD display
  writeDisplay();
  flashDisplay();
  // RGB LED
  LEDDisplay();
  // Logging
  //  logMode();
  //  logLumin();
  //  logTime();
  //  logTempTime();
  //  logLEDMode();
  //  logBTN();
  //  logDisplay();
}

// Debugger
void logMode() {
  Serial.print("MODE: ");
  Serial.println(STATE_MODE);
}
void logBTN() {
  Serial.print("BTN(LMR): ");
  Serial.print(BTN_VAL_L);
  Serial.print(BTN_VAL_M);
  Serial.println(BTN_VAL_R);
}
void logLumin() {
  Serial.print("LUMIN VFD: ");
  Serial.println(STATE_LUMIN);
  Serial.print("LUMIN LED: ");
  Serial.println(STATE_LED_LUMIN);
}
void logTime() {
  Serial.print("TIME: ");
  for (int i = 0; i < 5; ++i) {
    Serial.print(STATE_TIME[i]);
  }
  Serial.println(STATE_TIME[5]);
}
void logTempTime() {
  Serial.print("TEMP TIME: ");
  for (int i = 0; i < 5; ++i) {
    Serial.print(TIME_TEMP_TIME[i]);
  }
  Serial.println(TIME_TEMP_TIME[5]);
}
void logLEDMode() {
  Serial.print("LED MODE: ");
  Serial.println(STATE_LED_MODE);
}
void logDisplay() {
  Serial.print("DISPLAY: ");
  for (int i = 0; i < 4; ++i) {
    Serial.print(STATE_DISPLAY[i]);
  }
  Serial.println(STATE_DISPLAY[4]);
}

// Read RTC time
void getTime() {
  // read time
  DateTime currentTime = DS3231M.now();
  STATE_TIME[YEAR] = currentTime.year();
  STATE_TIME[MONTH] = currentTime.month();
  STATE_TIME[DATE] = currentTime.day();
  STATE_TIME[HOUR] = currentTime.hour();
  STATE_TIME[MIN] = currentTime.minute();
  STATE_TIME[SEC] = currentTime.second();
  // read temperature
  STATE_TEMP = DS3231M.temperature() + SET_TEMP_OFFSET;
}
// Push STATE_TIME to RTC
void pushTime() {
  DS3231M.adjust(DateTime(TIME_TEMP_TIME[YEAR], TIME_TEMP_TIME[MONTH], TIME_TEMP_TIME[DATE], TIME_TEMP_TIME[HOUR], TIME_TEMP_TIME[MIN], TIME_TEMP_TIME[SEC]));
}
// check power saving status
void powerSaving() {
  if (!STATE_POWER_SAVING_ON && STATE_TIME[HOUR] == SET_POWER_SAVING_ON_TIME[0] && STATE_TIME[MIN] == SET_POWER_SAVING_ON_TIME[1]) {
    // turn on power saving
    Serial.println(F("Power saving on."));
    STATE_POWER_SAVING_ON = true;
    POWER_SAVING_PREV_LUMIN = STATE_LUMIN;
    POWER_SAVING_PREV_LED_LUMIN = STATE_LED_LUMIN;
    STATE_LUMIN = SET_POWER_SAVING_LUMIN;
    STATE_LED_LUMIN = SET_POWER_SAVING_LED_LUMIN;
    putConfig();
  }
  if (STATE_POWER_SAVING_ON && STATE_TIME[HOUR] == SET_POWER_SAVING_OFF_TIME[0] && STATE_TIME[MIN] == SET_POWER_SAVING_OFF_TIME[1]) {
    // turn off power saving
    Serial.println(F("Power saving off."));
    STATE_POWER_SAVING_ON = false;
    STATE_LUMIN = POWER_SAVING_PREV_LUMIN;
    STATE_LED_LUMIN = POWER_SAVING_PREV_LED_LUMIN;
    putConfig();
  }
}

// display functions
/*
   Determines what to display base on STATE vars
*/
void writeDisplay() {
  switch (STATE_MODE) {
    case 0:
      // normal clock mode, show clock
      switch (CLOCK_MODE) {
        case 0:
          // show normal clock
          STATE_DISPLAY[0] = STATE_TIME[HOUR] / 10;
          STATE_DISPLAY[1] = STATE_TIME[HOUR] % 10;
          STATE_DISPLAY[2] = STATE_TIME[SEC] % 2 == 0 ? 0 : -1;  // only show colon at even seconds
          STATE_DISPLAY[3] = STATE_TIME[MIN] / 10;
          STATE_DISPLAY[4] = STATE_TIME[MIN] % 10;
          break;
        case 1:
          // show date and year
          if (millis() - CLOCK_DATE_YEAR_SHOW_TIME >= SET_CLOCK_SHORT_DUR) {
            // switch state
            CLOCK_DATE_YEAR_MODE += 1;
            CLOCK_DATE_YEAR_SHOW_TIME = millis(); // timestamp of mode transition
          }
          switch (CLOCK_DATE_YEAR_MODE) {
            case 0:
              // show date
              STATE_DISPLAY[0] = STATE_TIME[MONTH] / 10;
              STATE_DISPLAY[1] = STATE_TIME[MONTH] % 10;
              STATE_DISPLAY[2] = 2;  // only show bottom colon
              STATE_DISPLAY[3] = STATE_TIME[DATE] / 10;
              STATE_DISPLAY[4] = STATE_TIME[DATE] % 10;
              break;
            case 1:
              // show year
              STATE_DISPLAY[0] = STATE_TIME[YEAR] / 1000;
              STATE_DISPLAY[1] = STATE_TIME[YEAR] % 1000 / 100;
              STATE_DISPLAY[2] = -1;  // turn off colon
              STATE_DISPLAY[3] = STATE_TIME[YEAR] % 100 / 10;
              STATE_DISPLAY[4] = STATE_TIME[YEAR] % 10;
              break;
            default:
              // change back to normal clock mode
              CLOCK_DATE_YEAR_MODE = 0;
              CLOCK_MODE = 0;
              break;
          }
          break;
        case 2:
          // show temperature
          if (millis() - CLOCK_TEMP_TIME < SET_CLOCK_SHORT_DUR) {
            STATE_DISPLAY[0] = STATE_TEMP / 1000;
            STATE_DISPLAY[1] = STATE_TEMP / 100 % 10;
            STATE_DISPLAY[2] = 2; // decimal point
            STATE_DISPLAY[3] = STATE_TEMP / 10 % 10;
            STATE_DISPLAY[4] = 10;
          } else {
            // go back to normal clock mode
            CLOCK_MODE = 0;
          }
          break;
        case 3:
          // show custom greetings
          if (millis() - CLOCK_GREETING_TIME < SET_GREETING_CHAR_DUR) {
            STATE_DISPLAY[0] = SET_GREETING_WORDS[CLOCK_GREETING_INDEX];
            STATE_DISPLAY[1] = SET_GREETING_WORDS[CLOCK_GREETING_INDEX + 1];
            STATE_DISPLAY[2] = -1; // decimal point off
            STATE_DISPLAY[3] = SET_GREETING_WORDS[CLOCK_GREETING_INDEX + 2];
            STATE_DISPLAY[4] = SET_GREETING_WORDS[CLOCK_GREETING_INDEX + 3];
          } else {
            // next word
            CLOCK_GREETING_INDEX++;
            CLOCK_GREETING_TIME = millis(); // reset timer
            if (CLOCK_GREETING_INDEX > SET_GREETING_LENGTH - 4) {
              // go back to normal clock mode
              CLOCK_MODE = 0;
              CLOCK_GREETING_INDEX = 0;
            }
          }
          break;
        default:
          CLOCK_MODE = 0; // defualt
          break;
      }
      STATE_VFD_FLICKER = false;
      break;
    case 1:
      // time edit mode, blink clock
      switch (TIME_SET_LEVEL) {
        case 0:
          // edit time
          STATE_DISPLAY[0] = TIME_TEMP_TIME[HOUR] / 10;
          STATE_DISPLAY[1] = TIME_TEMP_TIME[HOUR] % 10;
          STATE_DISPLAY[2] = 0; // turn on both colon
          STATE_DISPLAY[3] = TIME_TEMP_TIME[MIN] / 10;
          STATE_DISPLAY[4] = TIME_TEMP_TIME[MIN] % 10;
          break;
        case 1:
          // edit date
          STATE_DISPLAY[0] = TIME_TEMP_TIME[MONTH] / 10;
          STATE_DISPLAY[1] = TIME_TEMP_TIME[MONTH] % 10;
          STATE_DISPLAY[2] = 2;  // only show bottom colon
          STATE_DISPLAY[3] = TIME_TEMP_TIME[DATE] / 10;
          STATE_DISPLAY[4] = TIME_TEMP_TIME[DATE] % 10;
          break;
        case 2:
          // edit year
          STATE_DISPLAY[0] = TIME_TEMP_TIME[YEAR] / 1000;
          STATE_DISPLAY[1] = TIME_TEMP_TIME[YEAR] % 1000 / 100;
          STATE_DISPLAY[2] = -1;  // turn off colon
          STATE_DISPLAY[3] = TIME_TEMP_TIME[YEAR] % 100 / 10;
          STATE_DISPLAY[4] = TIME_TEMP_TIME[YEAR] % 10;
          break;
      }
      STATE_VFD_FLICKER = true;
      break;
    case 2:
      // Lumin mode, display lumin as 0 ~ 10
      if (LUMIN_SET_LEVEL == 0) {  // VFD Lumin
        STATE_DISPLAY[0] = -1;  // no display
        STATE_DISPLAY[1] = -1;  // no display
        STATE_DISPLAY[2] = -1;  // no display
        STATE_DISPLAY[3] = (25 - (STATE_LUMIN - 5) / 10) / 10;
        STATE_DISPLAY[4] = (25 - (STATE_LUMIN - 5) / 10) % 10;
        STATE_VFD_FLICKER = true;
      } else if (LUMIN_SET_LEVEL == 1) {  // LED Lumin
        STATE_DISPLAY[0] = -1;  // no display
        STATE_DISPLAY[1] = -1;  // no display
        STATE_DISPLAY[2] = -1;  // no display
        STATE_DISPLAY[3] = (STATE_LED_LUMIN - 5) / 100;
        STATE_DISPLAY[4] = (STATE_LED_LUMIN - 5) / 10 % 10;
        STATE_VFD_FLICKER = false;
      }
      break;
    case 3:
      // LED mode, show normal clock (only LED is blinking)
      STATE_DISPLAY[0] = STATE_TIME[HOUR] / 10;
      STATE_DISPLAY[1] = STATE_TIME[HOUR] % 10;
      STATE_DISPLAY[2] = STATE_TIME[SEC] % 2 == 0 ? 0 : -1;  // only show colon at even seconds
      STATE_DISPLAY[3] = STATE_TIME[MIN] / 10;
      STATE_DISPLAY[4] = STATE_TIME[MIN] % 10;
      STATE_VFD_FLICKER = false;
      break;
    default:
      // reset display state in case it somehow ends up in a bizzare value
      STATE_MODE = 0;
      STATE_VFD_FLICKER = false;
      break;
  }
}
/*
   Display a single digit
   Steps:
   1. Clock in data on rising edge
   2. Latch out all data on falling edge
   3. PWM Blank pin to control brightness
*/
void flashDigit() {
  digitalWrite(PIN_VFD_LATCH, HIGH);
  // Clock 14 bits of data
  for (int i = 13; i >= 0; --i) {
    digitalWrite(PIN_VFD_CLK, LOW); // CLK LOW
    digitalWrite(PIN_VFD_DIN, VFD_TEMP[i]);  // Serial data
    digitalWrite(PIN_VFD_CLK, HIGH);  // CLK HIGH
  }
  // Latch data
  digitalWrite(PIN_VFD_LATCH, LOW);
  // PWM brightness control
  analogWrite(PIN_VFD_PWM, STATE_LUMIN);
}
/*
   Control full display by flashing digits real quick.
   Digits are flashed from left to right.
   Colon can be flashed with all the digits.
*/
void flashDisplay() {
  if (STATE_VFD_FLICKER) {
    // update per interval
    if (millis() - VFD_LAST_FLICKER >= SET_VFD_FLICKER_INTERVAL) {
      VFD_FLICKER_ON = !VFD_FLICKER_ON; // toggle flicker
      VFD_LAST_FLICKER = millis();  // save last flicker time
    }
    if (!VFD_FLICKER_ON) {
      // flash clear display
      analogWrite(PIN_VFD_PWM, 255);  // pull HIGH, which turns off the display
      return;
    }
  }
  // flash 4 number digits
  for (int i = 0; i < 4; ++i) {
    loadDisplaySeq(i, STATE_DISPLAY[i < 2 ? i : i + 1], STATE_DISPLAY[2] == 0 || STATE_DISPLAY[2] == 1, STATE_DISPLAY[2] == 0 || STATE_DISPLAY[2] == 2);
    flashDigit();
    delay(5);
  }
}
/*
   Clean display seq to 0
*/
void cleanDisplaySeq() {
  for (int i = 0; i < 14; ++i) {
    VFD_TEMP[i] = LOW;
  }
}
/*
   Helper function for building the right display shift sequence.
   Sequence should be reversed when displaying since shifiting to the registers starts at the largest index.
   Shift registers 0 ~ 13 corresponds to GRID_1 ~ 5, DOT_DOWN, DOT_UPPER, SEG_1 ~ 7
   For grid state, 0: both on, 1: up, 2: bottom
   "digit" parameter indicates which digit is the render target (0~3)
*/
void loadDisplaySeq(int digit, int num, bool dotTop, bool dotBot) {
  // clear previous data
  cleanDisplaySeq();
  if (num == -1) {
    // leave blank, don't display digit
    return;
  }
  // Load grid
  switch (digit) {
    case 0:
      // first digit
      VFD_TEMP[4] = HIGH;
      break;
    case 1:
      // second digit
      VFD_TEMP[3] = HIGH;
      break;
    case 2:
      // third digit
      VFD_TEMP[1] = HIGH;
      break;
    case 3:
      // fourth digit
      VFD_TEMP[0] = HIGH;
      break;
  }
  // Check colon grid
  if (dotTop || dotBot) {
    // set colon grid HIGH
    VFD_TEMP[2] = HIGH;
    // colon anodes
    if (dotBot) {
      VFD_TEMP[5] = HIGH;
    }
    if (dotTop) {
      VFD_TEMP[6] = HIGH;
    }
  }
  // Segment anodes (actual display numbers)
  switch (num) {
    case 0:
      for (int i = 0; i < 7; ++i) {
        VFD_TEMP[i + 7] = NUM_0[i];
      }
      break;
    case 1:
      for (int i = 0; i < 7; ++i) {
        VFD_TEMP[i + 7] = NUM_1[i];
      }
      break;
    case 2:
      for (int i = 0; i < 7; ++i) {
        VFD_TEMP[i + 7] = NUM_2[i];
      }
      break;
    case 3:
      for (int i = 0; i < 7; ++i) {
        VFD_TEMP[i + 7] = NUM_3[i];
      }
      break;
    case 4:
      for (int i = 0; i < 7; ++i) {
        VFD_TEMP[i + 7] = NUM_4[i];
      }
      break;
    case 5:
      for (int i = 0; i < 7; ++i) {
        VFD_TEMP[i + 7] = NUM_5[i];
      }
      break;
    case 6:
      for (int i = 0; i < 7; ++i) {
        VFD_TEMP[i + 7] = NUM_6[i];
      }
      break;
    case 7:
      for (int i = 0; i < 7; ++i) {
        VFD_TEMP[i + 7] = NUM_7[i];
      }
      break;
    case 8:
      for (int i = 0; i < 7; ++i) {
        VFD_TEMP[i + 7] = NUM_8[i];
      }
      break;
    case 9:
      for (int i = 0; i < 7; ++i) {
        VFD_TEMP[i + 7] = NUM_9[i];
      }
      break;
    case 10:
      for (int i = 0; i < 7; ++i) {
        VFD_TEMP[i + 7] = ALP_C[i];
      }
      break;
    case 11:
      for (int i = 0; i < 7; ++i) {
        VFD_TEMP[i + 7] = ALP_H[i];
      }
      break;
    case 12:
      for (int i = 0; i < 7; ++i) {
        VFD_TEMP[i + 7] = ALP_E[i];
      }
      break;
    case 13:
      for (int i = 0; i < 7; ++i) {
        VFD_TEMP[i + 7] = ALP_L[i];
      }
      break;
    case 14:
      for (int i = 0; i < 7; ++i) {
        VFD_TEMP[i + 7] = ALP_N[i];
      }
      break;
    case 15:
      for (int i = 0; i < 7; ++i) {
        VFD_TEMP[i + 7] = ALP_W1[i];
      }
      break;
    case 16:
      for (int i = 0; i < 7; ++i) {
        VFD_TEMP[i + 7] = ALP_W2[i];
      }
      break;
    case 17:
      for (int i = 0; i < 7; ++i) {
        VFD_TEMP[i + 7] = ALP_Y[i];
      }
      break;
    case 18:
      for (int i = 0; i < 7; ++i) {
        VFD_TEMP[i + 7] = ALP_U[i];
      }
      break;
    case 19:
      for (int i = 0; i < 7; ++i) {
        VFD_TEMP[i + 7] = ALP_S[i];
      }
      break;
    case 20:
      for (int i = 0; i < 7; ++i) {
        VFD_TEMP[i + 7] = ALP_M1[i];
      }
      break;
    case 21:
      for (int i = 0; i < 7; ++i) {
        VFD_TEMP[i + 7] = ALP_M2[i];
      }
      break;
  }
}

// control button functions
/*
    Detect button press on falling edge.
    There are three control buttons: Left, Mid, and Right (L.M.R)
    In Clock Mode, each control buttons triggers a new mode:
    L: Edit Time Mode
    M: Brightness Mode
    R: RGB LED Mode
    Exit to Clock Mode by pressing the same button again.
    The other two non-trigger buttons in each mode adjust the values up or down.
*/
void detectControls() {
  // read button values
  BTN_PREV_VAL_L = BTN_VAL_L;
  BTN_VAL_L = digitalRead(PIN_BTN_L);
  BTN_PREV_VAL_M = BTN_VAL_M;
  BTN_VAL_M = digitalRead(PIN_BTN_M);
  BTN_PREV_VAL_R = BTN_VAL_R;
  BTN_VAL_R = digitalRead(PIN_BTN_R);
  // Enter mode
  switch (STATE_MODE) {
    case 0:
      // Clock Mode
      controlClock();
      break;
    case 1:
      // Edit Time Mode
      controlTime();
      break;
    case 2:
      // Brightness Mode
      controlLumin();
      break;
    case 3:
      // RGB LED Mode
      controlLED();
      break;
    default:
      // reset mode if somehow it ended up in a bizzare state
      STATE_MODE = 0;
      break;
  }
}
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

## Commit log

2021-08-22 added hardware docs
    [VFD_CLOCK_V3_Copper_Signal_Bot.gbr, VFD_CLOCK_V3_Copper_Signal_Top.gbr, VFD_CLOCK_V3_Legend_Bot.gbr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]
2021-08-24 Added case design file
    [vfd_back.dxf, vfd_front.dxf]
2021-08-24 new setting LED staturation and hue
2021-08-24 updated BOM
    [BOM.csv]
